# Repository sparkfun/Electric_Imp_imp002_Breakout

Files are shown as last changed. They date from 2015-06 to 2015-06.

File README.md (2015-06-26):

SparkFun Electric Imp imp002 Breakout
============================

Electric Imp imp002 Breakout

[*Electric Imp imp002 Breakout (BOB-12958)*](https://www.sparkfun.com/products/12958)

The imp002 is a surface mount Electric Imp module with its own breakout board and more pins than the original imp001 card.

Repository Contents
-------------------
* **/Documentation** - SVG files of the board layout.
* **/Hardware** - Eagle PCB layout files
* **/Production** - Files to support SparkFun production

Documentation
--------------

* **[Hookup Guide](https://learn.sparkfun.com/tutorials/electric-imp-breakout-hookup-guide)** - Basic hookup guide

Product Versions
----------------

* [BOB-12958](https://www.sparkfun.com/products/12958)- Hardware version 1.0. 

Version History
---------------

License Information
-------------------

This product is _**open source**_! 

Please review the LICENSE.md file for license information. 

If you have any questions or concerns on licensing, please contact techsupport@sparkfun.com.

Distributed as-is; no warranty is given.

- Your friends at SparkFun.

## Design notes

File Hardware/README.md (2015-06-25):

SparkFun Electric Imp imp002 Breakout Board Design Files
========================================================

The .sch and .brd files hare are Eagle CAD schematic and PCB design files from SparkFun Electronics.
A freeware version of Eagle can be found [here](http://www.cadsoftusa.com/download-eagle/freeware/). 

License
---------
This product is open source! 
The hardware is released under [Creative Commons ShareAlike 4.0 International](https://creativecommons.org/licenses/by-sa/4.0/).

Please use, reuse, and modify these files as you see fit. Please maintain attribution to SparkFun Electronics and release anything derivative under the same license.

Distributed as-is; no warranty is given.

- Your friends at SparkFun.

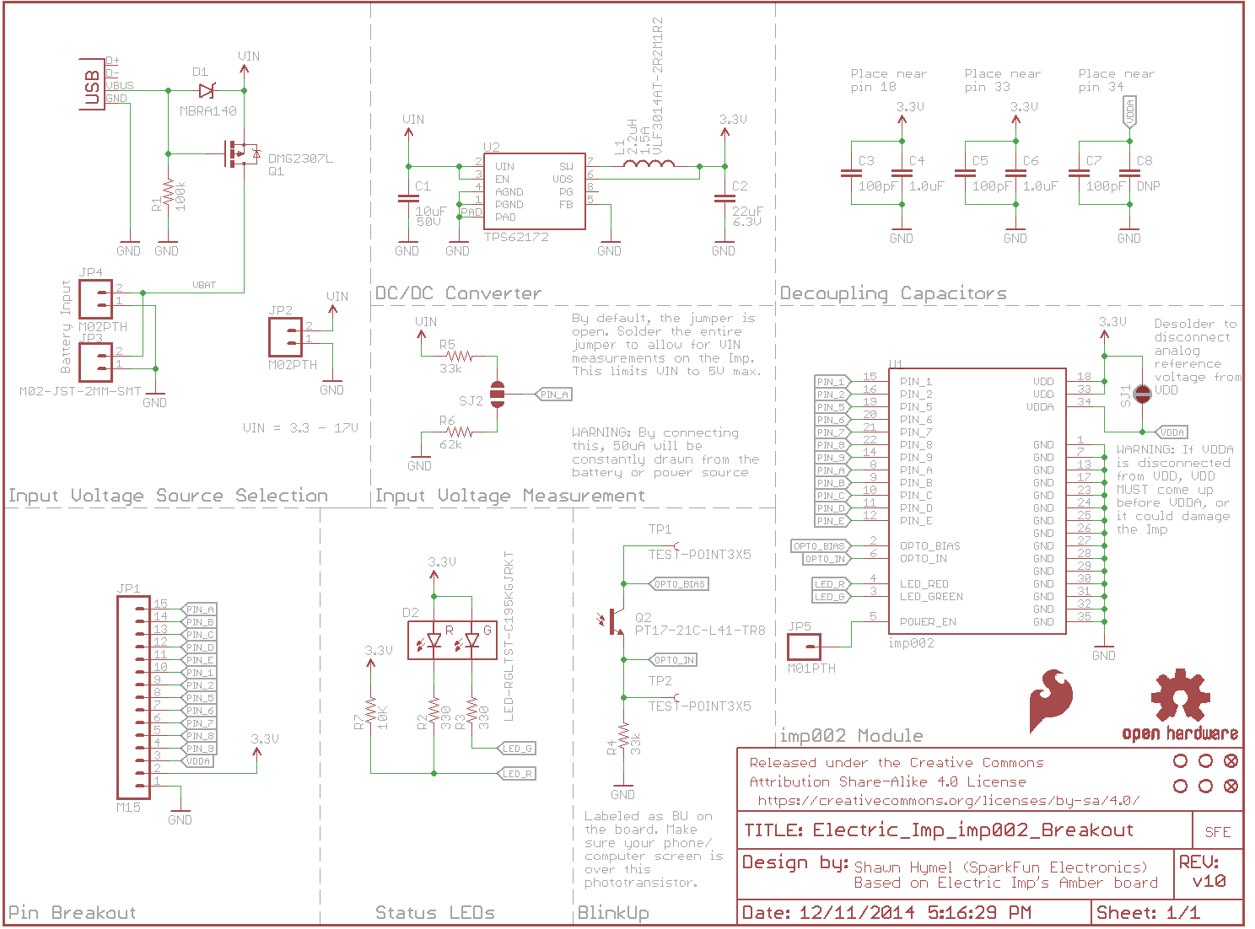
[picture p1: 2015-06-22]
Documentation/Electric_Imp_imp002_Breakout_schematic.png

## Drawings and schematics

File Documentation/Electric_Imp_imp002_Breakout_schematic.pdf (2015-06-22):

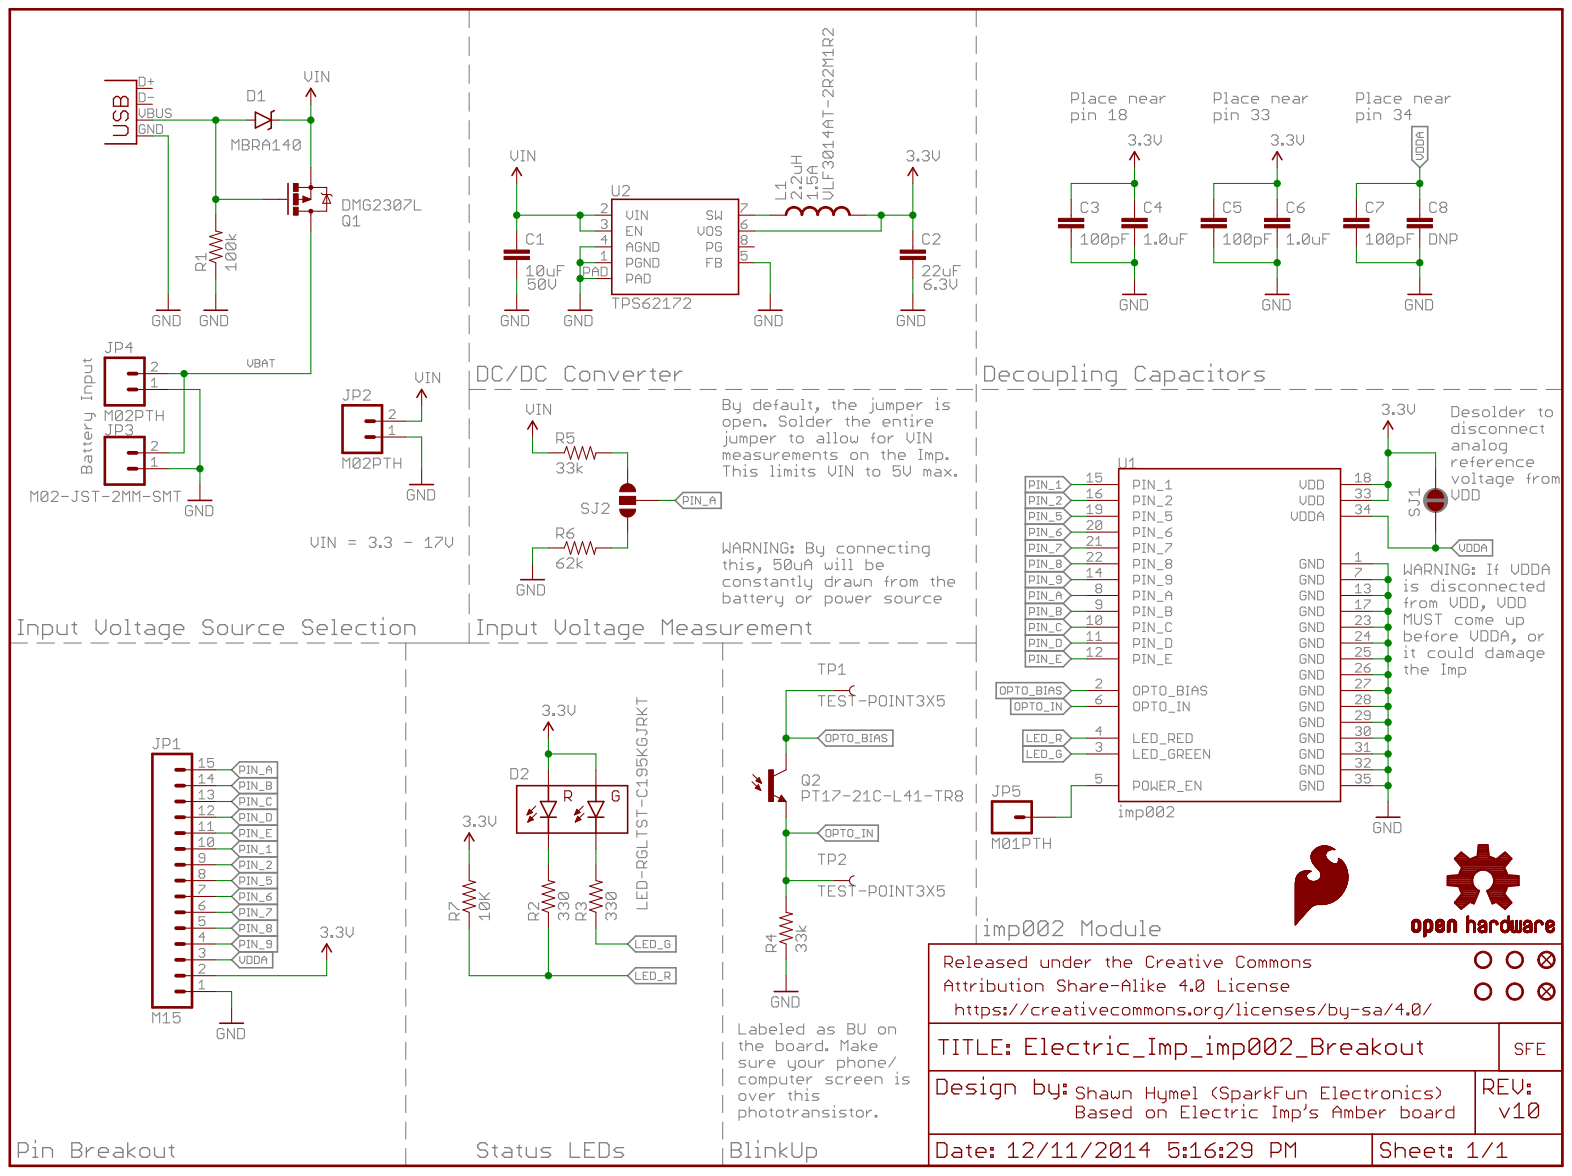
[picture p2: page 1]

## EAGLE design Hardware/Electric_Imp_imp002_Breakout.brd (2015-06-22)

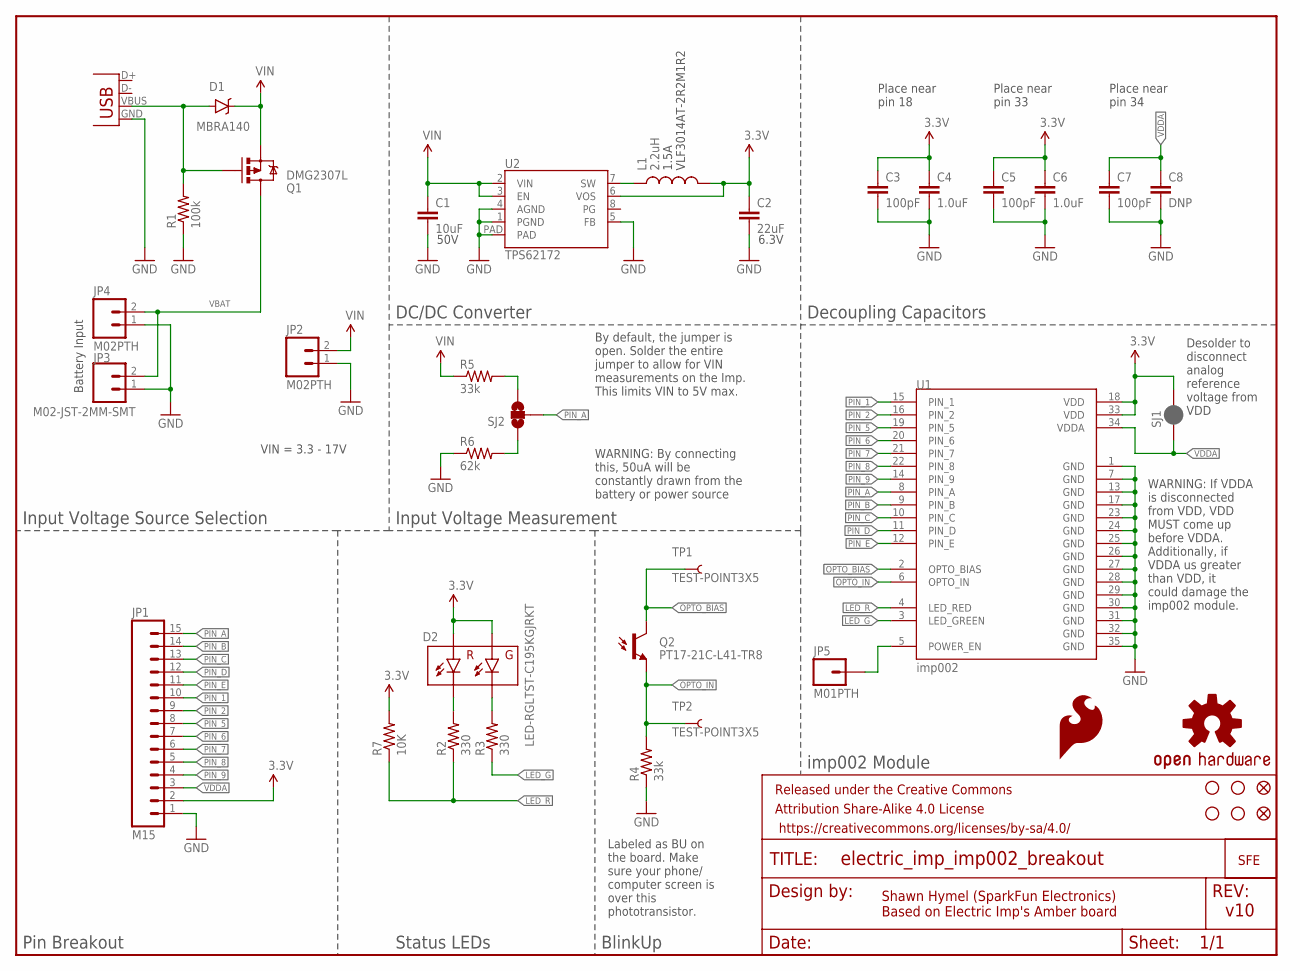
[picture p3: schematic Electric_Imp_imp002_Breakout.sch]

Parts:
C1: 10uF; 1210
C2: 22uF; 0805
C3, C5, C7: 100pF; 0603-CAP
C4, C6: 1.0uF; 0603-CAP
C8: DNP; 0603-CAP
D1: MBRA140; SMA-DIODE
D2: LED-RGLTST-C195KGJRKT; LTST-C195KGJRKT
FID1, FID2: FIDUCIAL1X2; FIDUCIAL-1X2
FRAME1: FRAME-LETTER; CREATIVE_COMMONS
JP1: M15; 1X15
JP2, JP4: M02PTH; 1X02
JP3: M02-JST-2MM-SMT; JST-2-SMD
JP5: M01PTH; 1X01
L1: 2.2uH; VLF4012A
LOGO1: OSHW-LOGOS; OSHW-LOGO-S
LOGO2: SFE_LOGO_FLAME.1_INCH; SFE_LOGO_FLAME_.1
Q1: DMG2307L; SOT23-3
Q2: PT17-21C-L41-TR8
R1: 100k; 0603-RES
R2, R3: 330; 0603-RES
R4, R5: 33k; 0603-RES
R6: 62k; 0603-RES
R7: 10K; 0603-RES
SJ1: JUMPER-PAD-2-NC_BY_PASTE; PAD-JUMPER-2-NC_BY_PASTE_YES_SILK
SJ2: JUMPER-PAD-3-NOFULL_BOX_SILK; PAD-JUMPER-3-NO_YES_SILK_FULL_BOX
STANDOFF1, STANDOFF2, STANDOFF3, STANDOFF4: STAND-OFF
TP1, TP2: TEST-POINT3X5; PAD.03X.05
U1: imp002; ELECTRIC_IMP_IMP002
U2: TPS62172; WSON-8-PAD
U$9: SFE_LOGO_NAME_WEB; SFE-NEW-WEBLOGO
X1: USBSMD; USB-MINIB

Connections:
3.3V: C2.1, C3.1, C4.1, C5.1, C6.1, D2.P$1 (GA), D2.P$2 (RA), JP1.2, L1.P$2 (2), R7.2, SJ1.2, U1.18 (VDD), U1.33 (VDD), U2.6 (VOS)
GND: C1.2, C2.2, C3.2, C4.2, C5.2, C6.2, C7.2, C8.2, JP1.1, JP2.1, JP3.1 (2), JP4.1, R1.1, R4.1, R6.1, U1.1 (GND), U1.7 (GND), U1.13 (GND), U1.17 (GND), U1.23 (GND), U1.24 (GND), U1.25 (GND), U1.26 (GND), U1.27 (GND), U1.28 (GND), U1.29 (GND), U1.30 (GND), U1.31 (GND), U1.32 (GND), U1.35 (GND), U2.1 (PGND), U2.4 (AGND), U2.5 (FB), U2.PAD, X1.GND
LED_G: R3.1, U1.3 (LED_GREEN)
LED_R: R2.1, R7.1, U1.4 (LED_RED)
unnamed: L1.P$1 (1), U2.7 (SW)
unnamed: D1.A, Q1.1 (G), R1.2, X1.VBUS
unnamed: D2.P$4 (RC), R2.2
unnamed: D2.P$3 (GC), R3.2
unnamed: R5.2, SJ2.3
unnamed: R6.2, SJ2.1
OPTO_BIAS: Q2.C, TP1.P$1, U1.2 (OPTO_BIAS)
OPTO_IN: Q2.E, R4.2, TP2.P$1, U1.6 (OPTO_IN)
PIN_1: JP1.10, U1.15 (PIN_1)
PIN_2: JP1.9, U1.16 (PIN_2)
PIN_5: JP1.8, U1.19 (PIN_5)
PIN_6: JP1.7, U1.20 (PIN_6)
PIN_7: JP1.6, U1.21 (PIN_7)
PIN_8: JP1.5, U1.22 (PIN_8)
PIN_9: JP1.4, U1.14 (PIN_9)
PIN_A: JP1.15, SJ2.2, U1.8 (PIN_A)
PIN_B: JP1.14, U1.9 (PIN_B)
PIN_C: JP1.13, U1.10 (PIN_C)
PIN_D: JP1.12, U1.11 (PIN_D)
PIN_E: JP1.11, U1.12 (PIN_E)
POWER_EN: JP5.1, U1.5 (POWER_EN)
VBAT: JP3.2 (1), JP4.2, Q1.3 (D)
VDDA: C7.1, C8.1, JP1.3, SJ1.1, U1.34 (VDDA)
VIN: C1.1, D1.C, JP2.2, Q1.2 (S), R5.1, U2.2 (VIN), U2.3 (EN)

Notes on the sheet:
50V
6.3V
1.5A
VLF3014AT-2R2M1R2
Place near pin 18
Place near pin 33
Place near pin 34
Desolder to disconnect analog reference voltage from VDD
Input Voltage Source Selection
Input Voltage Measurement
DC/DC Converter
Decoupling Capacitors
imp002 Module
Pin Breakout
Status LEDs
BlinkUp
By default, the jumper is open. Solder the entire jumper to allow for VIN measurements on the Imp. This limits VIN to 5V max.
Battery Input
Shawn Hymel (SparkFun Electronics) Based on Electric Imp's Amber board
v10
VIN = 3.3 - 17V
WARNING: By connecting this, 50uA will be constantly drawn from the battery or power source
WARNING: If VDDA is disconnected from VDD, VDD MUST come up before VDDA. Additionally, if VDDA us greater than VDD, it could damage the imp002 module.
Labeled as BU on the board. Make sure your phone/ computer screen is over this phototransistor.

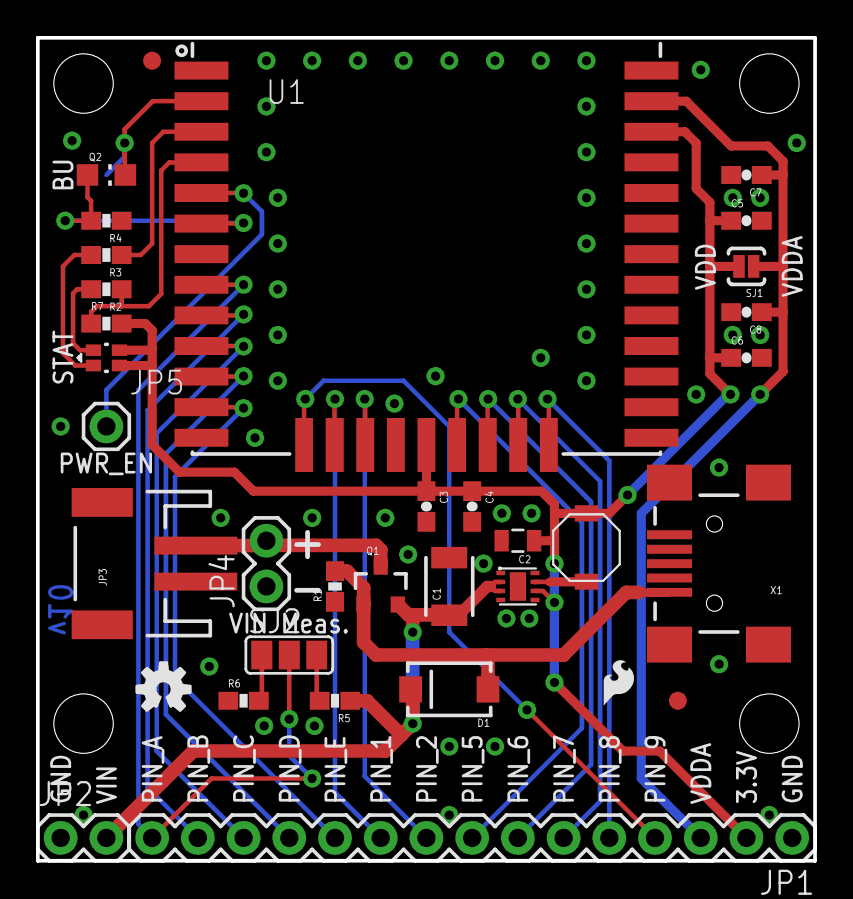
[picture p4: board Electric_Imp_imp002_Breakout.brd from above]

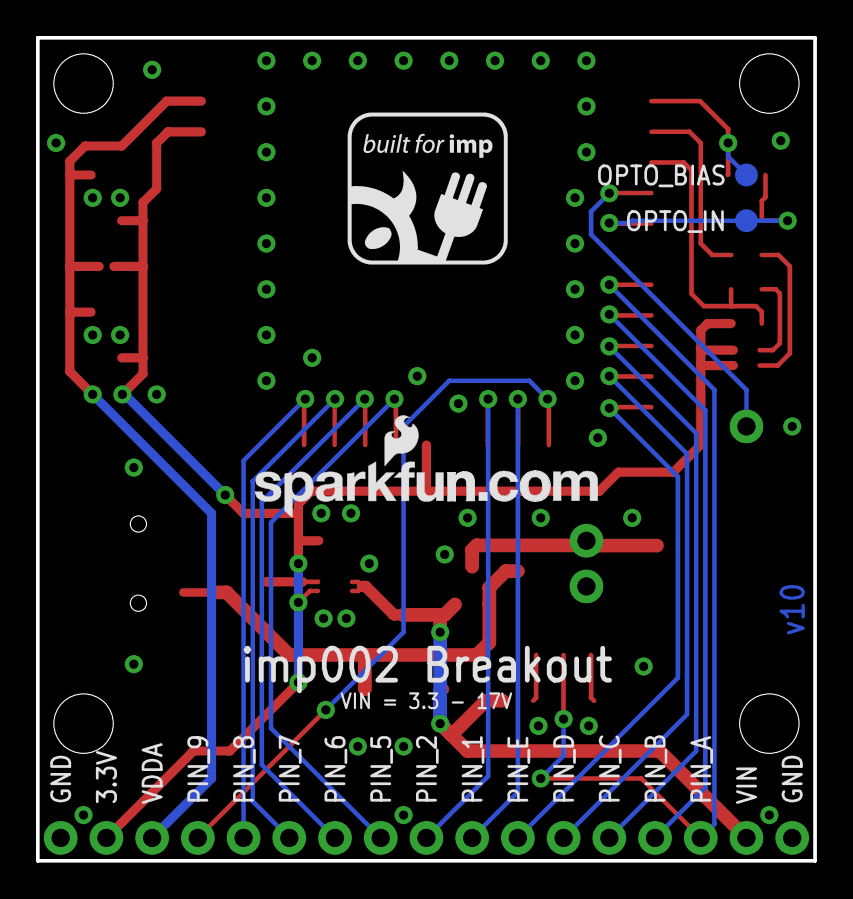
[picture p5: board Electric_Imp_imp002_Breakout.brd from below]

Board: 2 copper layers, 43.2 x 45.7 mm, 42 parts (3 on the bottom side), 28 nets.

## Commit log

2014-05-15 Created blank schematic and updated .gitignore
    [Electric_Imp_imp002_Breakout.brd, Electric_Imp_imp002_Breakout.sch]
2014-05-19 Created initial schematic and part placement
    [Electric_Imp_imp002_Breakout.brd, Electric_Imp_imp002_Breakout.sch]
2014-05-21 Added automatic voltage source selector and battery level monitor in schematic
    [Electric_Imp_imp002_Breakout.brd, Electric_Imp_imp002_Breakout.sch]
2014-05-27 Finished v01 prototype for review
    [Electric_Imp_imp002_Breakout.brd, Electric_Imp_imp002_Breakout.sch]
2014-05-27 Made changes from review. Fixed VIn sense divider. Updated packages to remove $ symbols. Added +/- silk to battery. Added voltage input range text on sch and brd. Moved decoup caps on bottom of imp t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
    [Electric_Imp_imp002_Breakout.brd, Electric_Imp_imp002_Breakout.sch]
2014-05-27 Changed 68k resistor to 62k
    [Electric_Imp_imp002_Breakout.brd, Electric_Imp_imp002_Breakout.sch]
2014-11-05 Added silk to the 3-way jumper, moved marking for dual-color diode to outside footprint, and changed phototransistor gain resistor to 33k
    [Electric_Imp_imp002_Breakout.brd, Electric_Imp_imp002_Breakout.sch]
2014-11-05 Changed rev number to v10
    [Electric_Imp_imp002_Breakout.brd, Electric_Imp_imp002_Breakout.sch]
2014-11-11 Added 10k pullup on LED_R line. Added warning notes to the solder jumpers.
    [Electric_Imp_imp002_Breakout.brd, Electric_Imp_imp002_Breakout.sch]
2014-11-19 Fixed 3-way jumper name. Added PROD_ID to components lacking it. Added device name to phototransistor in schematic.
    [Electric_Imp_imp002_Breakout.brd, Electric_Imp_imp002_Breakout.sch]
2014-11-19 Fixed issues from GitHub for reds.
    [Electric_Imp_imp002_Breakout.brd, Electric_Imp_imp002_Breakout.sch]
2015-06-22 Created PNG and PDF versions of the schematic.
2015-06-22 Fixed note about VDD/VDDA jumper in schematic.
    [Electric_Imp_imp002_Breakout.brd, Electric_Imp_imp002_Breakout.sch]

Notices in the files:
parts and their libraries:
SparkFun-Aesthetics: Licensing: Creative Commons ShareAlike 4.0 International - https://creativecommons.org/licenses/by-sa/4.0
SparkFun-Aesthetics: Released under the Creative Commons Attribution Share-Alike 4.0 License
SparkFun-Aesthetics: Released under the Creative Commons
